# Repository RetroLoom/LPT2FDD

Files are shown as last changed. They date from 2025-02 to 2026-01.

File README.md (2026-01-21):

# LPT2FDD
LPT to Floppy Drive adapter for supported vintage laptops. This revision is specifically designed for the Sharp PC-9000 / 9030 series laptops but may also work on clones or subsequent Sharp laptops as well. The laptop must support floppy protocol through the LPT port for this to work. This project also serves as an archive for pin sets required for LPT floppy protocols.


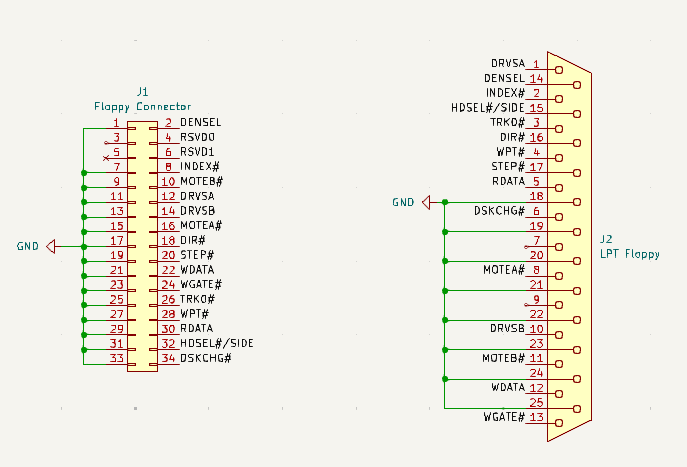
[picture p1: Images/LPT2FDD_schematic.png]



v0.5 Adds a jumper resistor between pins 21 and 22 to allow compatibility with Compaq laptop external floppy detection. Currently it is recommended to use a 1k resistor for extra safety. This should trigger the Compaq laptop to recognize a connected floppy drive (if supported by laptop), but external power needs to be provided separately to the floppy drive. 

More information and discussion can be found here - https://www.vogons.org/viewtopic.php?t=105093.
 
## Build of Materials and Installation
Other than the PCB, there are really only two other connectors required to build the LPT2FDD.
Use with a standard single drive floppy cable with the twist. Powering the floppy drive externally is required. A ps/2 to 5v adapter will be provided soon.

Pin 3 of the DC3 connector may need to be removed for keyed floppy cables. 

### Example Sources
34-Pin DC3 Connector
https://www.aliexpress.us/item/3256806835271080.html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

D-SUB DB-25 Male or Female
https://www.aliexpress.us/item/3256805300852948.html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

Single Drive Floppy cable
https://www.aliexpress.us/item/3256805300852948.html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

## Support the Developer
This project is brought to you free and open source, but it is not free to develop. If you like this project please consider supporting this and future developments. 

https://www.patreon.com/RetroLoom

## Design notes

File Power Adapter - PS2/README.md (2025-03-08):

# LPT2FDD Power Adapter with PS/2
PS/2 Adapter for powering an external floppy drive or other device. 



## Credits
Added symbol and footprint library - https://github.com/4x1md/kicad_libraries

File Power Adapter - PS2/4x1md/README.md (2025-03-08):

# Custom KiCad Libraries

Custom KiCad components used in my projects.

## Examples

### General Symbols and Footprints

  Symbols I

  Footprints I

### PJ-311D SMD 3.5mm Headphones Jack

  PJ-311D

  PJ-311D

  Since April 11, 2017 this footprint is available in official KiCad [Connectors.pretty](https://github.com/KiCad/Connectors.pretty) library.

### PJ-31060 SMD 3.5mm Headphones Jack

  PJ-31060

  PJ-31060

  Since April 11, 2017 this footprint is available in official KiCad [Connectors.pretty](https://github.com/KiCad/Connectors.pretty) library.

### SPDT Slide Switch

  The footprint is designed for 0.8x0.45mm pins.

  SPDT Slide Switch

  SPDT Slide Switch

### PJ-320E Through Hole 3.5mm Headphones Jack With Microphone

  PJ-320E

  PJ-320E

  PJ-320E

  Since April 11, 2017 this footprint is available in official KiCad [Connectors.pretty](https://github.com/KiCad/Connectors.pretty) library.

### PJ-320D/DS SMD 3.5mm Headphones Jack With Microphone

  PJ-320D/DS

  PJ-320D/DS

  PJ-320D/DS

  Since April 11, 2017 this footprint is available in official KiCad [Connectors.pretty](https://github.com/KiCad/Connectors.pretty) library.

### 3.5mm Headphones Jack With Microphone, 4 pins, 6 contacts

  P3.5mm headphones with microphone jack

  P3.5mm headphones with microphone jack

### Microampermeter For PCB Mounting

  Tuning meter from an old radio receiver which I used in my [QRP SWR Meter](https://github.com/4x5dm/qrp_swr_meter) project.

  Microampermeter

  Microampermeter

### Mini USB Connectors

  Microampermeter

  Microampermeter

  Microampermeter

### Mini-DIN 6 Pin Connector

  Mini-DIN 6 Pin Connector

  Mini-DIN 6 Pin Connector

  Mini-DIN 6 Pin Connector

### Philmore 30-20001 SPDT Switch

  Philmore 30-20001 SPDT Switch

### Cliff UT1x SPDT Switch

  Cliff UT1x SPDT Switch

### Seiko MS621FE-FL11E Backup Battery

  Seiko MS621FE-FL11E

## GPS Modules

### GlobalTop Gms-g9 GNSS Module

  GlobalTop Gms-g9

  GlobalTop Gms-g9

### Quectel L80 GPS Module

  L80 GPS

  L80 GPS

  L80 GPS

## Components Library Installation

1. Download the [custom_kicad_symbols](https://github.com/4x5dm/kicad_libraries/tree/master/custom_kicad_symbols) folder to your computer.
2. Open Eeschema editor.
3. Go to ```Preferences``` menu and select ```Component Libraries```.

  Step I
4. In the window which will be opened click ```Add``` button and select the library you saved.

  Step II

## Footprints Library Installation

1. Download the [custom_kicad_footprints.pretty](https://github.com/4x5dm/kicad_libraries/tree/master/custom_kicad_footprints.pretty) folder to your computer. Each file in this folder represents a footprint.
2. Open KiCad PCB editor.
3. Go to ```Preferences``` menu and select ```Footprint Libraries Manager```.

  Step I
4. In the wizard window which will be opened select ```Files on my computer``` option and click ```Next```.

  Step II
5. Find the downloaded folder and click ```Next```.

  Step III
6. You'll see the properties of the new library. If all is OK, click ```Next```.

  Step IV
7. Select required library viibility and click ```Finish```.

  Step V

## Questions? Suggestions?
You are more than welcome to contact me with any questions, suggestions or propositions regarding this project. You can:

1. Visit [my QRZ.COM page](https://www.qrz.com/db/4X5DM)
2. Visit [my Facebook profile](https://www.facebook.com/Dima.Meln)
3. Write me an email to iosaaris =at= gmail dot com

## How to Support or Say Thanks

If you like this project, or found here some useful information and want to say thanks, or encourage me to do more, you can buy me a coffee!



"Buy Me A Coffee" (https://www.buymeacoffee.com/4x1md)

You can aslo make a donation with PayPal:



---

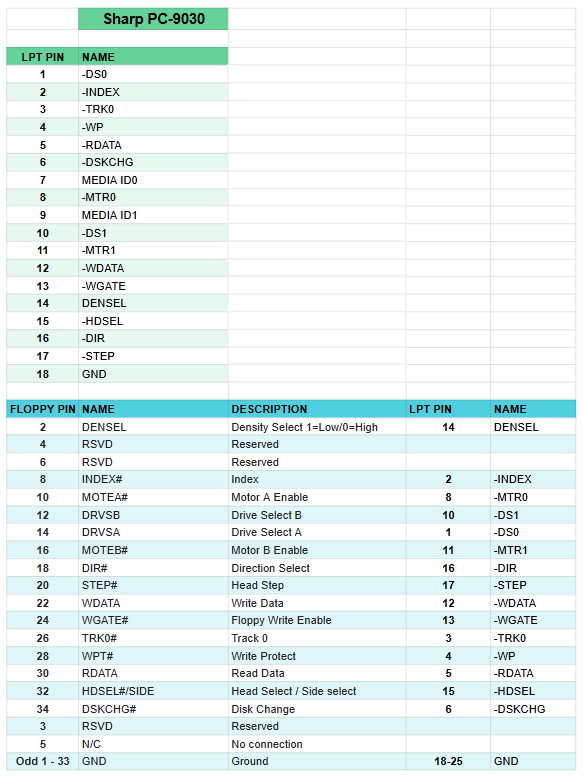
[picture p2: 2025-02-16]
Images/LPT2FDD_pinout.png

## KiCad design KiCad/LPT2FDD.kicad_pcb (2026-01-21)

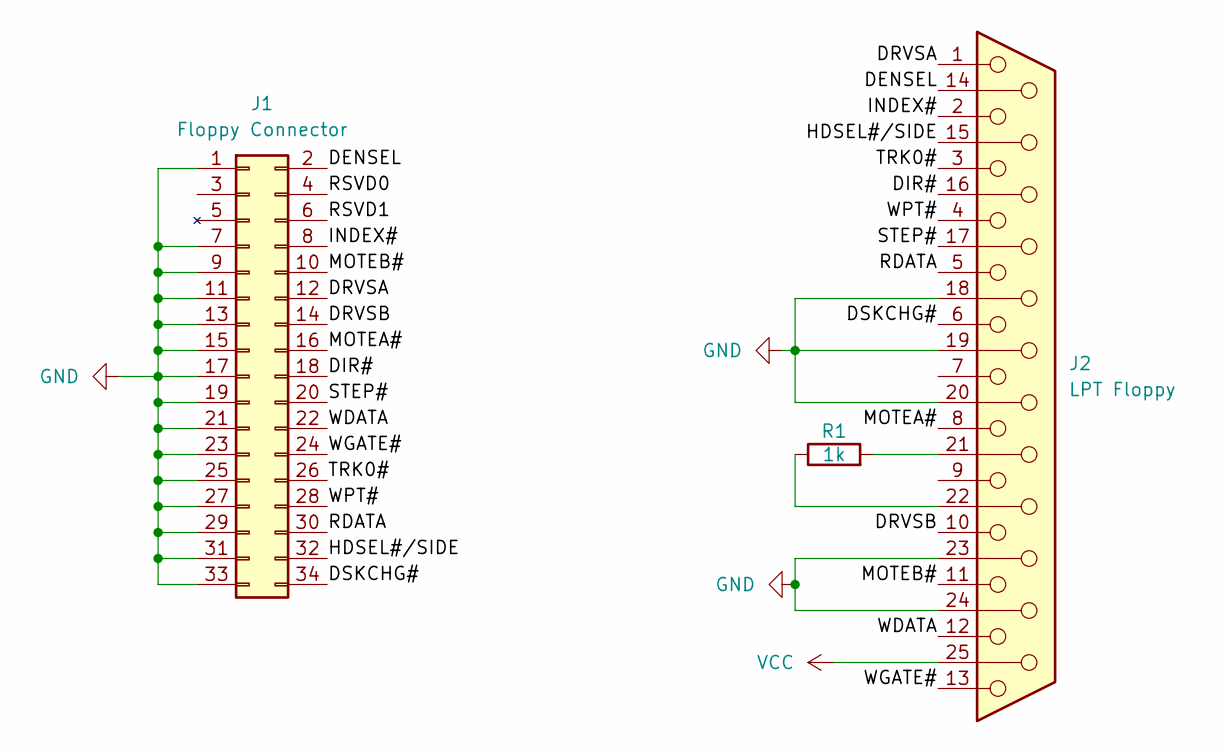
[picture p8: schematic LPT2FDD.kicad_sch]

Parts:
J1: Floppy Connector; IDC-Header_2x17_P2.54mm_Vertical
J2: LPT Floppy; DSUB-25_Male_Horizontal_P2.77x2.84mm_EdgePinOffset4.94mm_Ho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
R1: 1k; R_0805_2012Metric_Pad1.20x1.40mm_HandSolder

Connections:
/DENSEL: J1.2 (DENSEL), J2.14 (DENSEL)
/DIR#: J1.18 (DIR#), J2.16 (-DIR)
/DRVSA: J1.12 (DRVSB), J2.1 (-DSO)
/DRVSB: J1.14 (DRVSA), J2.10 (-DS1)
/DSKCHG#: J1.34 (DSKCHG#), J2.6 (-DSKCHG)
/HDSEL#/SIDE: J1.32 (HDSEL#/SIDE), J2.15 (-HDSEL)
/INDEX#: J1.8 (INDEX#), J2.2 (-INDEX)
/MOTEA#: J1.16 (MOTEB#), J2.8 (-MTR0)
/MOTEB#: J1.10 (MOTEA#), J2.11 (-MTR1)
/RDATA: J1.30 (RDATA), J2.5 (-RDATA)
/RSVD0: J1.4 (RSVD)
/RSVD1: J1.6 (RSVD)
/STEP#: J1.20 (STEP#), J2.17 (-STEP)
/TRK0#: J1.26 (TRK0#), J2.3 (-TRK0)
/WDATA: J1.22 (WDATA), J2.12 (-WDATA)
/WGATE#: J1.24 (WGATE#), J2.13 (-WGATE)
/WPT#: J1.28 (WPT#), J2.4 (-WP)
GND: J1.1 (GND), J1.7 (GND), J1.9 (GND), J1.11 (GND), J1.13 (GND), J1.15 (GND), J1.17 (GND), J1.19 (GND), J1.21 (GND), J1.23 (GND), J1.25 (GND), J1.27 (GND), J1.29 (GND), J1.31 (GND), J1.33 (GND), J2.18 (GND), J2.19, J2.20, J2.23, J2.24
unnamed: J2.21, R1.2
unnamed: J2.22, R1.1
VCC: J2.25

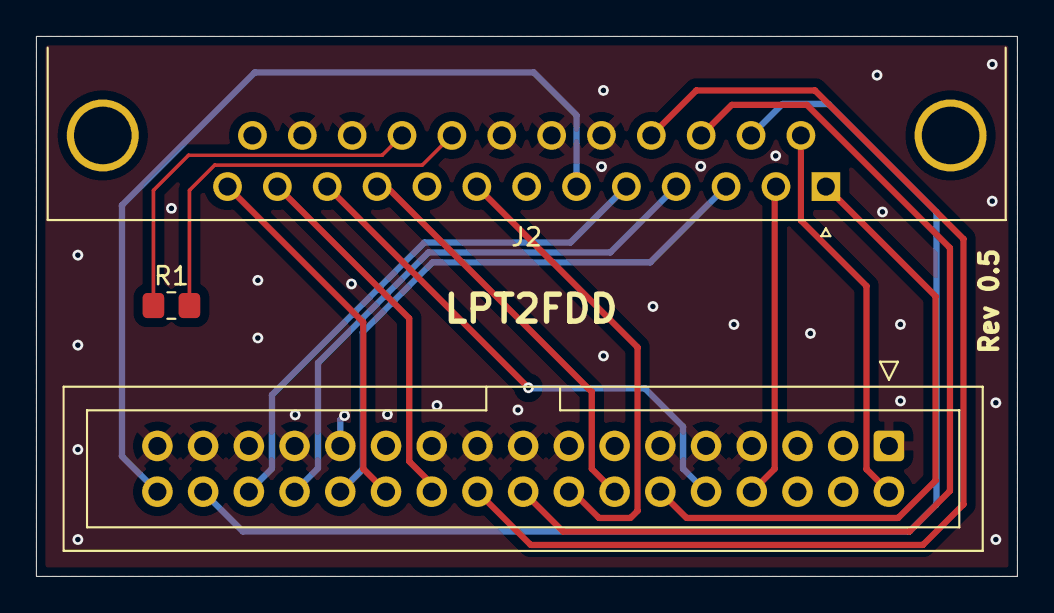
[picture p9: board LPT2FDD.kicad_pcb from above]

Board: 2 copper layers, 54.5 x 30.0 mm, 3 parts (0 on the bottom side), 18 nets.

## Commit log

2025-01-22 Initial Design - 0.4
    [LPT2FDD.kicad_pcb, LPT2FDD.kicad_sch]
2025-03-08 PS/2 Power Adapter v0.2
    [Power Adapater - PS2.kicad_pcb, Power Adapater - PS2.kicad_sch]
2026-01-21 v0.5 Add pin 21 and pin 22 jumper for Compaq compatibility
    [LPT2FDD.kicad_pcb, LPT2FDD.kicad_sch]
2026-01-21 PS/2 Power Adapter v0.3 - Better labeling, filename fix
    [Power Adapater - PS2.kicad_pcb, Power Adapater - PS2.kicad_sch, Power Adapter - PS2.kicad_pcb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]
